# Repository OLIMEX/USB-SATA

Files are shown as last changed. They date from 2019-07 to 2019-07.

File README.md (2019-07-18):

# USB-SATA
USB to SATA converter

# License
Hardware is with CERN OHL v1.2 license

Software is with GPL3 license

Documentation is with CC BY-SA 4.0 license

# USB-SATA Benchmark

[Reference](https://www.thomas-krenn.com/en/wiki/Linux_I/O_Performance_Tests_using_dd)

## Commands
### Streaming I/O
    dd if=/dev/zero of=/mnt/testfile bs=1G count=1 oflag=direct
    dd if=/dev/zero of=/mnt/testfile bs=512M count=1 oflag=direct
    dd if=/dev/zero of=/mnt/testfile bs=256M count=1 oflag=direct

### Latency
    hdparm -W0 /dev/sdx
    dd if=/dev/zero of=/mnt/testfile bs=512 count=1000 oflag=direct

## Results

| Board | Streaming I/O | Latency  |
| ---|---:| ---:|
| PC | 30.2 MB/s | 37.3938 ms |
| A20-MICRO | 28.4 MB/s | 30.5117 ms |
| A10-LIME  | 7.6 MB/s | 33.1223 ms |
| A13-OLXn  | 30.0 MB/s | - |
| A64-OLXn  | 31.5 MB/s | 36.6841 ms |

### PC
#### Streaming I/O
    1073741824 bytes (1.1 GB, 1.0 GiB) copied, 35.5515 s, 30.2 MB/s
** 30.2 MB/s **
### Latency
    512000 bytes (512 kB, 500 KiB) copied, 37.3938 s, 13.7 kB/s
** 37.3938 ms **

## A20-OLinuXino-MICRO
### Streaming I/O
    536870912 bytes (537 MB) copied, 18.9142 s, 28.4 MB/s
** 28.4 MB/s **
### Latency
    512000 bytes (512 kB) copied, 30.5117 s, 16.8 kB/s
** 30.5117 ms ** 

## A10-Lime
### Streaming I/O
    268435456 bytes (268 MB) copied, 35.4505 s, 7.6 MB/s
** 7.6 MB/s **
### Latency
    512000 bytes (512 kB) copied, 33.1223 s, 15.5 kB/s
** 33.1223 ms ** 

## A13-OLinuXino
### Streaming I/O
    268435456 bytes (268 MB) copied, 8.96246 s, 30.0 MB/s
** 30.0 MB/s **

## A64-OLinuXino
### Streaming I/O
    536870912 bytes (537 MB, 512 MiB) copied, 17.0416 s, 31.5 MB/s
** 31.5 MB/s **
### Latency
    512000 bytes (512 kB, 500 KiB) copied, 36.6841 s, 14.0 kB/s
** 36.6841 ms **

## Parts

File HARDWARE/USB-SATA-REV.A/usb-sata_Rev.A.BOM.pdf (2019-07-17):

usb-sata_Rev.A

Designation | Quan-tity | Designator | Package
USB-A MALE | 1 | P3 | USB-A-MALE-SMD
SATA-PWA-07 | 1 | CONN1 | SATA-MALE-7
0402 100 NF 10% 10VDC | 12 | C1,C3,C5,C6,C11,C1 4,C15,C16,C18,C21, C23,C25 | C0402
0603 10 UF 10V 20% | 7 | C2,C4,C12,C13,C17, C22,C24 | C_0603_5MIL_DWS
0402 10 NF X7R 50VDC | 5 | C7,C8,C9,C10,C19 | C0402
0402 20 PF +-0.25 PF | 2 | C26,C27 | C0402
0603 LED RED | 1 | D1 | LED_0603_KA
0603 LED GREEN | 1 | D2 | LED_0603_KA
0402 1 K 5% | 2 | R1,R3 | R_0402_5MIL_DWS
0402 10 K 5% | 4 | R2,R4,R5,R8 | R_0402_5MIL_DWS
0402 4.7 K 5% | 3 | R6,R9,R10 | R_0402_5MIL_DWS
0402 12K 1% | 1 | R7 | R_0402_5MIL_DWS
0402 1 M 5% | 1 | R12 | R_0402_5MIL_DWS
AP1231-3.3V (SOT23-5) | 1 | U1 | SOT-23-5
93LC46C-I/SN (n.a.) | 0 | U2 | SOIC-8
JM20329-LGCA3E | 1 | U3 | LQFP48
SMD3225 12 MHz 10ppm 20pF | 1 | X1 | TSX-3.2x2.5mm_GND(3)
WS02R | 1 | P1 | LIPO_BAT-CON2DW02R
0402 47 K 5% | 1 | R11 | R_0402_5MIL_DWS
0603 1 UF 10V 20% | 1 | C20 | C_0603_5MIL_DWS

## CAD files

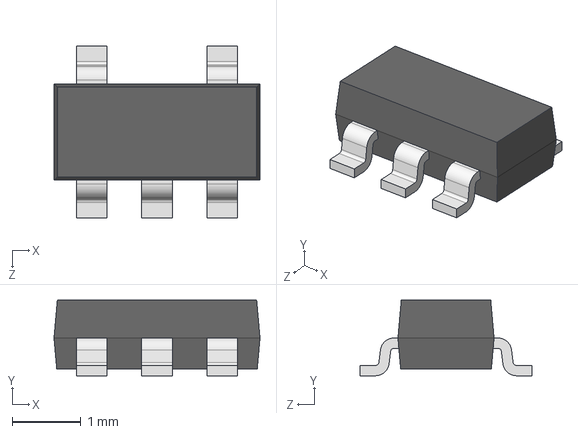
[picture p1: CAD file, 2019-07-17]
HARDWARE/USB-SATA-REV.A/3d/SOT-23-5.step
3.00 x 1.10 x 2.50 mm

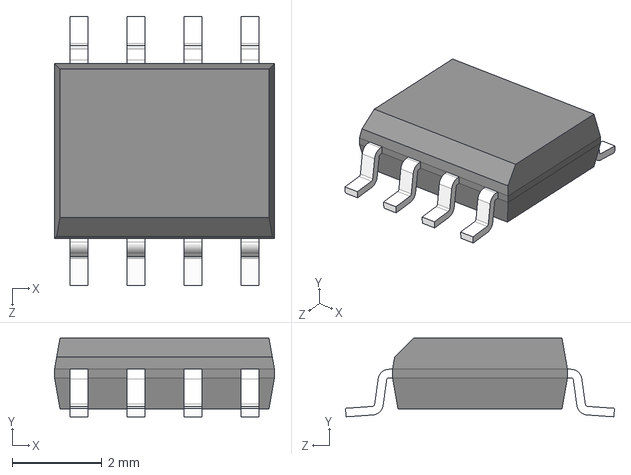
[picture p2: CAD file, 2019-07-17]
HARDWARE/USB-SATA-REV.A/3d/SO-8_150mil---SN65HVDA1050AQDRQ1.STEP
4.90 x 1.75 x 5.99 mm

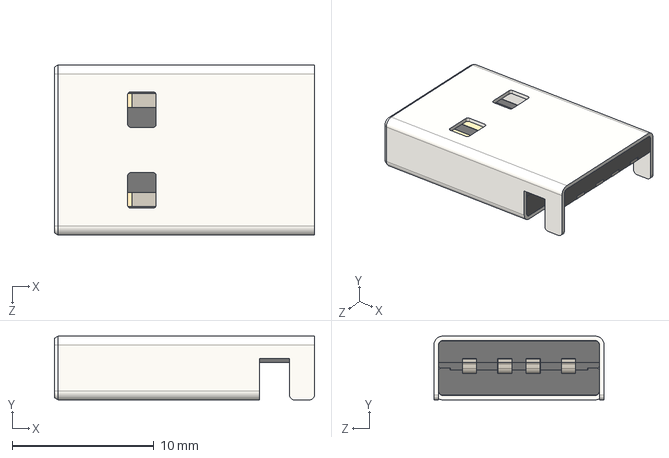
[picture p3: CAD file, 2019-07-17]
HARDWARE/USB-SATA-REV.A/3d/USB-A-MALE.step
18.3 x 4.50 x 12.0 mm

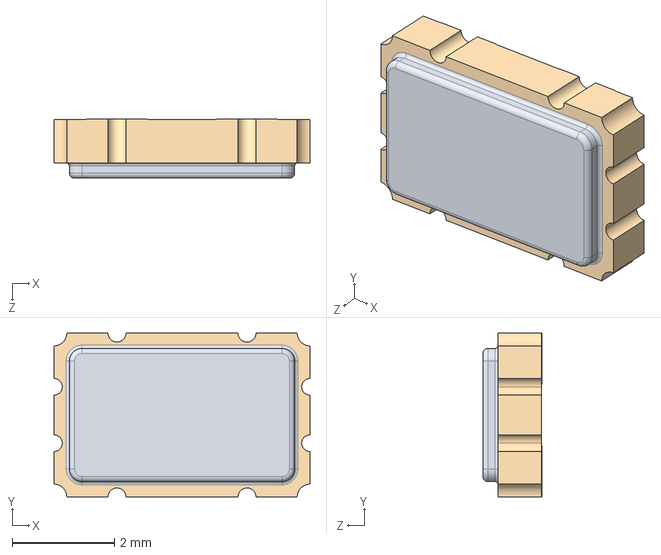
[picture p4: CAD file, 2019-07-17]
HARDWARE/USB-SATA-REV.A/3d/QSG5032.step
5.00 x 3.20 x 1.16 mm

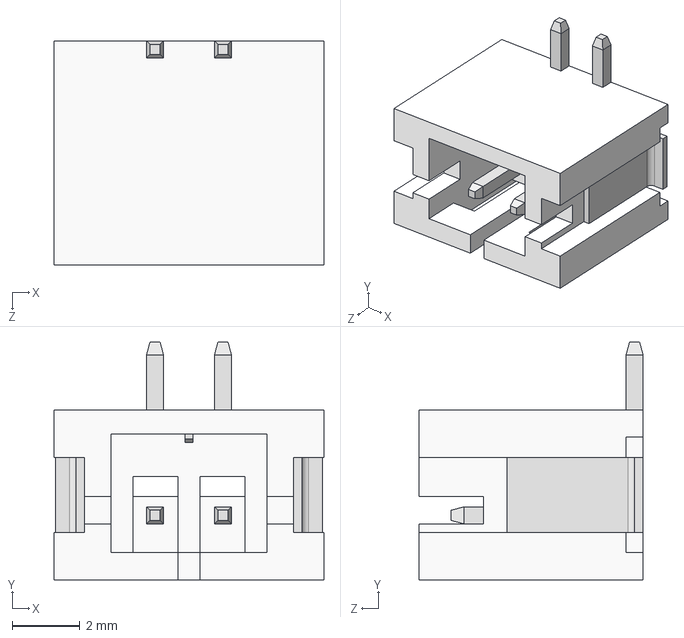
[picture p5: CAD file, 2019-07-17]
HARDWARE/USB-SATA-REV.A/3d/JST_B2B-PH-SM4-TB(DW02R).step
7.95 x 7.00 x 6.60 mm

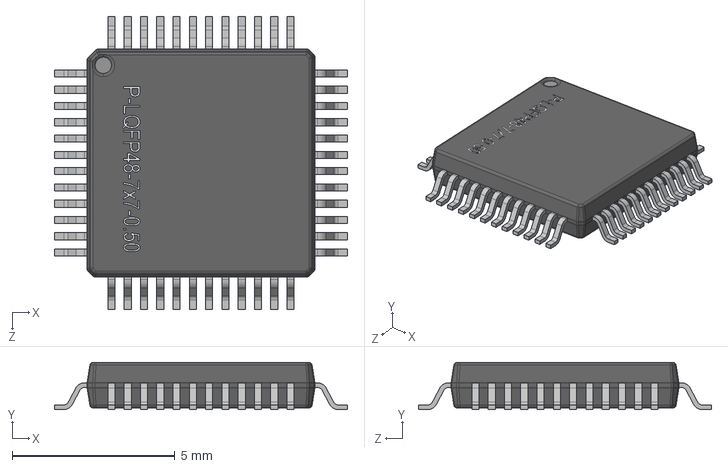
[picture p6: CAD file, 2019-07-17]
HARDWARE/USB-SATA-REV.A/3d/LQFP48-7x7-0_50.step
9.00 x 1.45 x 9.00 mm

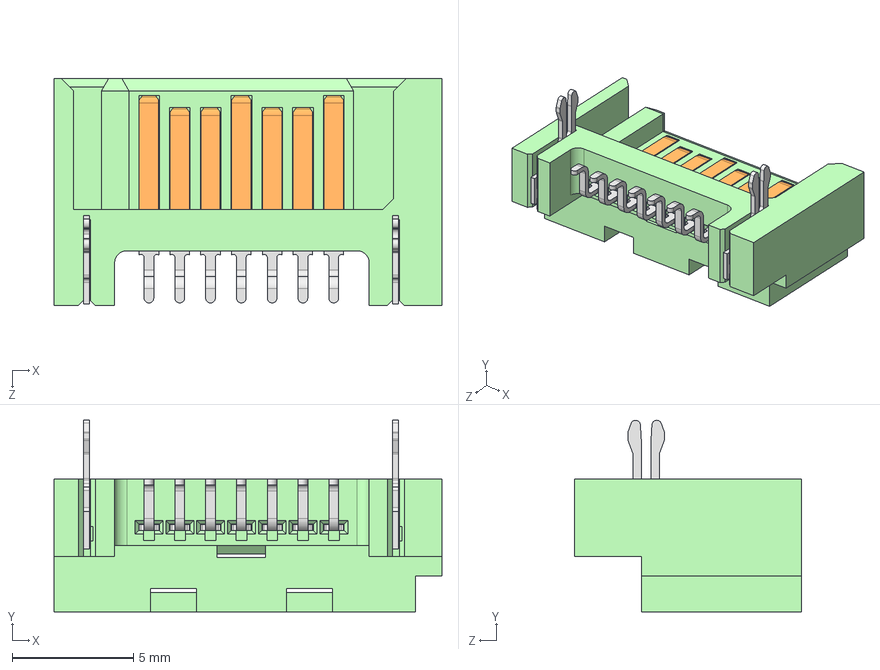
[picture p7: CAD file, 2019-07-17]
HARDWARE/USB-SATA-REV.A/3d/10035692-011.STEP
16.0 x 7.90 x 9.35 mm

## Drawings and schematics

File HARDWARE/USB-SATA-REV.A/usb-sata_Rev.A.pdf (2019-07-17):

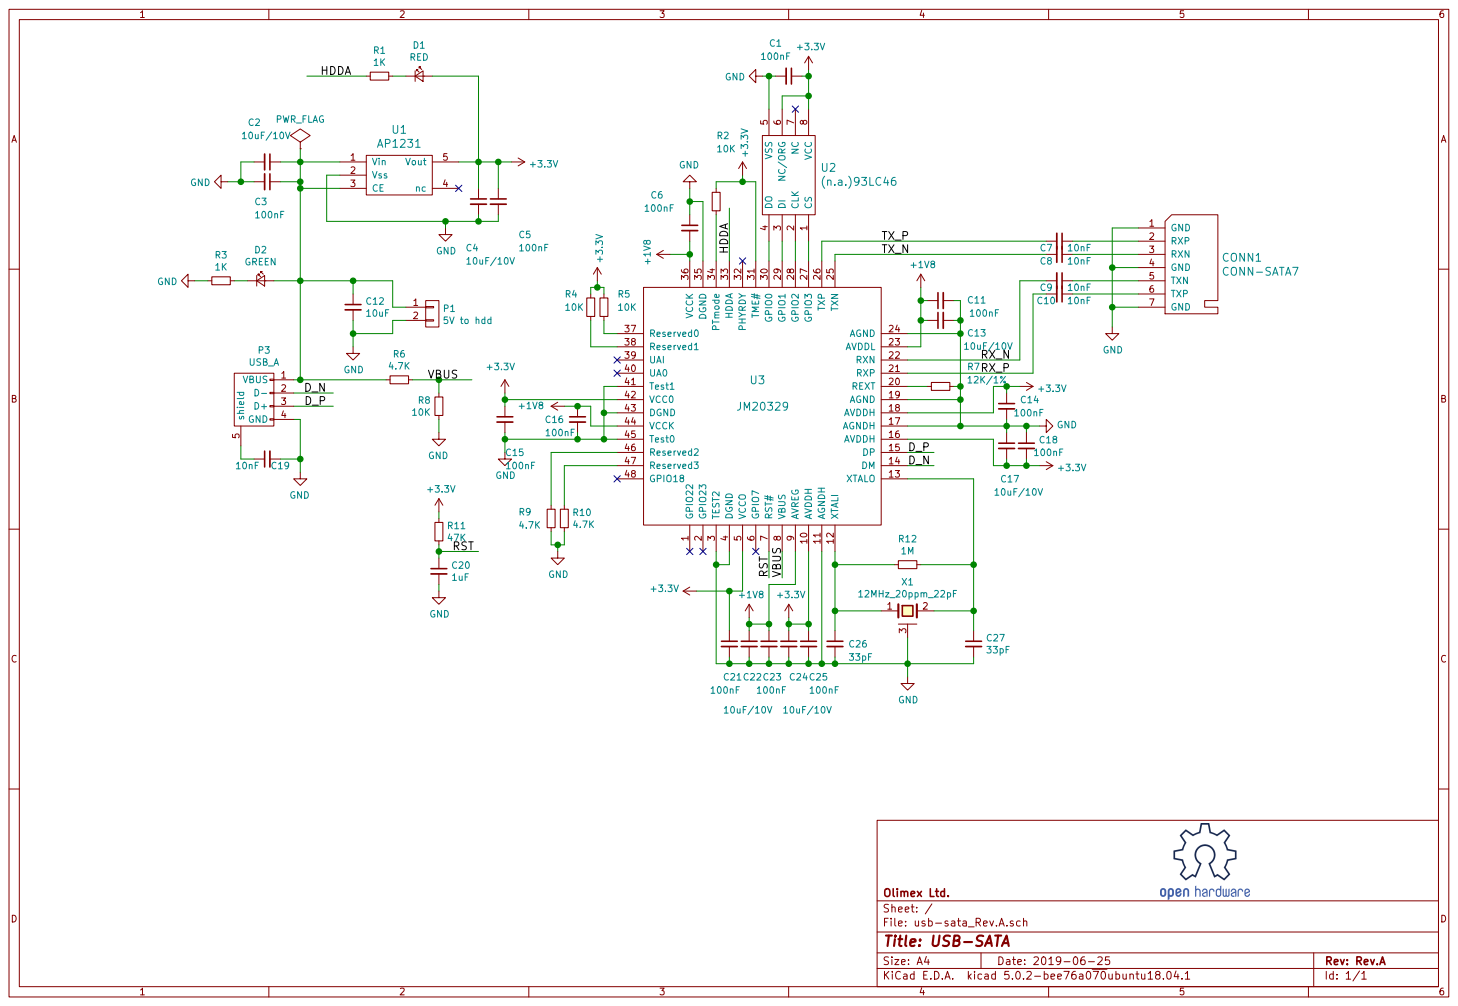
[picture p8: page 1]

3 GPIO0 30 TME# 31 PHYRDY 32 HDDA 33 PTmode 34 DGND 35 VCCK 36 Reserved0 37 Reserved1 38 UAI 39 DGND

2 REXT 20 RXP 21 RXN 22 AVDDL 23 AGND 24 TXN 25 TXP 26 GPIO3 27 GPIO2 28 GPIO1 29 TEST2

1 AVDDH 10 AGNDH 11 XTALI 12 XTALO 13 DM 14 DP 15 AVDDH 16 AGNDH 17 AVDDH 18 AGND 19 GPIO23

File: usb-sata_Rev.A.sch Sheet: / Olimex Ltd. GPIO22

Id: 1/1 Title: USB-SATA

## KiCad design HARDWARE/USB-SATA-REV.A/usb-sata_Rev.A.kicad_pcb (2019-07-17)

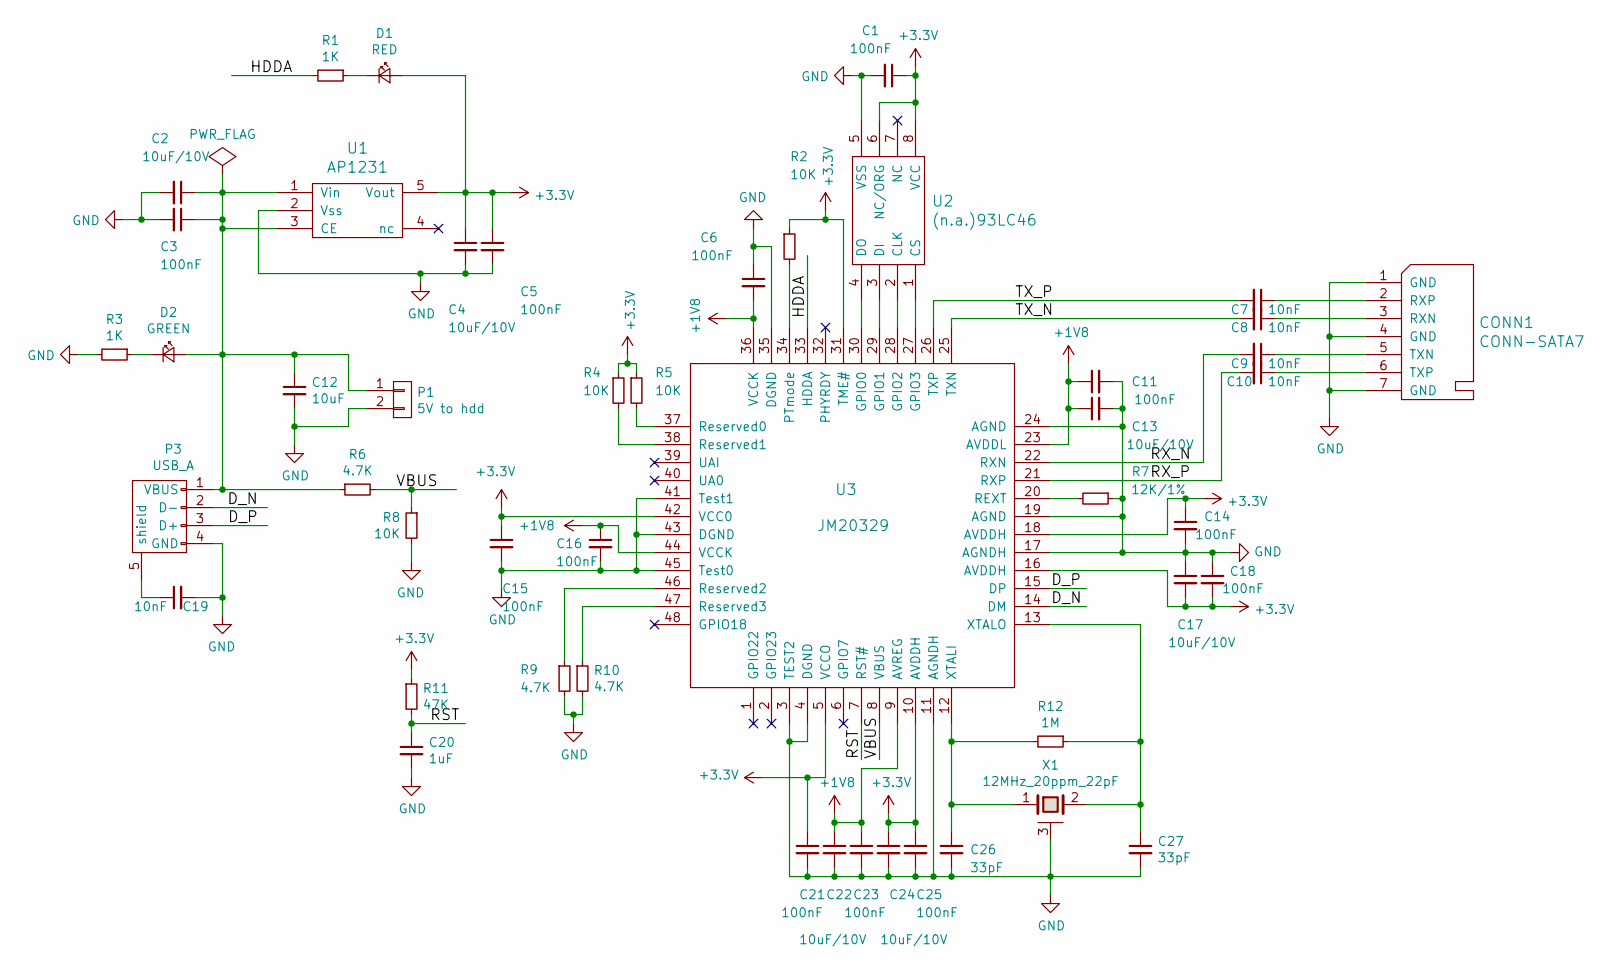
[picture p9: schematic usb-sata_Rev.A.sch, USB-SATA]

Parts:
C1, C3, C5, C6, C11, C14, C15, C16, C18, C21, C23, C25: 100nF; C0402
C2, C4, C13, C17, C22, C24: 10uF/10V; C_0603_5MIL_DWS
C7, C8, C9, C10, C19: 10nF; C0402
C12: 10uF; C_0603_5MIL_DWS
C20: 1uF; C0402
C26, C27: 33pF; C0402
CONN1: CONN-SATA7; SATA-MALE-7
D1: RED; LED_0603_KA
D2: GREEN; LED_0603_KA
P1: 5V to hdd; LIPO_BAT-CON2DW02R
P3: USB_A; USB-A-MALE-SMD
R1, R3: 1K; R_0402_5MIL_DWS
R2, R4, R5, R8: 10K; R_0402_5MIL_DWS
R6, R9, R10: 4.7K; R_0402_5MIL_DWS
R7: 12K/1%; R_0402_5MIL_DWS
R11: 47K; R_0402_5MIL_DWS
R12: 1M; R_0402_5MIL_DWS
U1: AP1231; SOT-23-5
U2: (n.a.)93LC46; SOIC-8
U3: JM20329; LQFP48
X1: 12MHz_20ppm_22pF

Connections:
+1V8: C6.2, C11.1, C13.1, C16.1, C22.1, C23.1, U3.9 (AVREG), U3.23 (AVDDL), U3.36 (VCCK), U3.44 (VCCK)
+3V3: C1.1, C4.1, C5.1, C14.1, C15.1, C17.2, C18.2, C21.1, C24.1, C25.1, D1.2 (A), R2.1, R4.1, R5.1, R11.1, U1.5 (Vout), U2.6 (NC/ORG), U2.8 (VCC), U3.5 (VCCO), U3.10 (AVDDH), U3.16 (AVDDH), U3.18 (AVDDH), U3.31 (TME#), U3.42 (VCC0)
/D_N: P3.2 (D-), U3.14 (DM)
/D_P: P3.3 (D+), U3.15 (DP)
/HDDA: R1.2, U3.33 (HDDA)
/RST: C20.1, R11.2, U3.7 (RST#)
/RX_N: C9.2, U3.22 (RXN)
/RX_P: C10.2, U3.21 (RXP)
/TX_N: C8.2, U3.25 (TXN)
/TX_P: C7.2, U3.26 (TXP)
/VBUS: R6.2, R8.1, U3.8 (VBUS)
GND: C1.2, C2.2, C3.2, C4.2, C5.2, C6.1, C11.2, C12.2, C13.2, C14.2, C15.2, C16.2, C17.1, C18.1, C19.2, C20.2, C21.2, C22.2, C23.2, C24.2, C25.2, C26.2, C27.2, CONN1.1 (GND), CONN1.4 (GND), CONN1.7 (GND), P1.2, P3.4 (GND), R3.2, R7.1, R8.2, R9.2, R10.2, U1.2 (Vss), U2.5 (VSS), U3.3 (TEST2), U3.4 (DGND), U3.11 (AGNDH), U3.17 (AGNDH), U3.19 (AGND), U3.24 (AGND), U3.35 (DGND), U3.41 (Test1), U3.43 (DGND), U3.45 (Test0), X1.3 (case)
unnamed: C7.1, CONN1.2 (RXP)
unnamed: C8.1, CONN1.3 (RXN)
unnamed: C9.1, CONN1.5 (TXN)
unnamed: C10.1, CONN1.6 (TXP)
unnamed: C2.1, C3.1, C12.1, D2.2 (A), P1.1, P3.1 (VBUS), R6.1, U1.1 (Vin), U1.3 (CE)
unnamed: C19.1, P3.5 (shield)
unnamed: C26.1, R12.2, U3.12 (XTALI), X1.1
unnamed: C27.1, R12.1, U3.13 (XTALO), X1.2
unnamed: D1.1 (K), R1.1
unnamed: D2.1 (K), R3.1
unnamed: R2.2, U3.34 (PTmode)
unnamed: R4.2, U3.38 (Reserved1)
unnamed: R5.2, U3.37 (Reserved0)
unnamed: R7.2, U3.20 (REXT)
unnamed: R9.1, U3.46 (Reserved2)
unnamed: R10.1, U3.47 (Reserved3)
unnamed: U2.1 (CS), U3.27 (GPIO3)
unnamed: U2.2 (CLK), U3.28 (GPIO2)
unnamed: U2.3 (DI), U3.29 (GPIO1)
unnamed: U2.4 (DO), U3.30 (GPIO0)

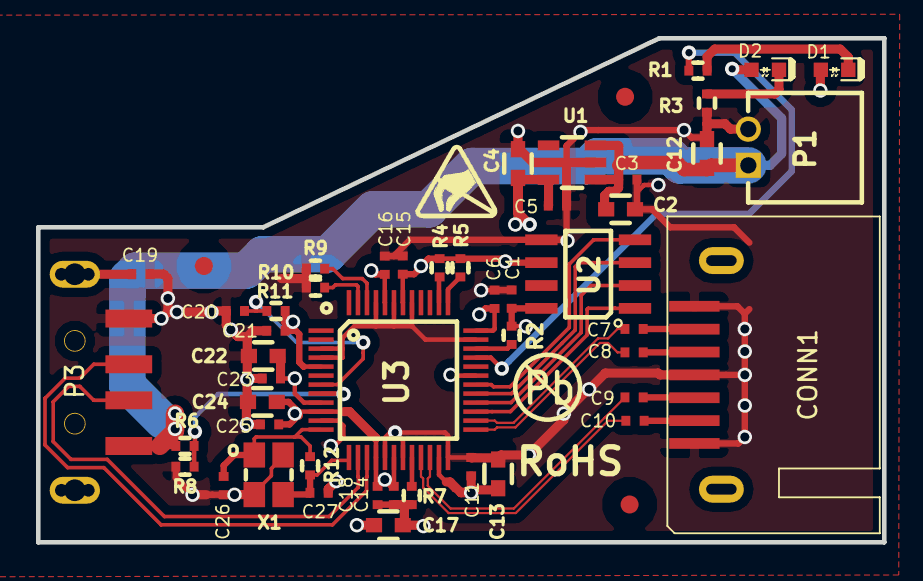
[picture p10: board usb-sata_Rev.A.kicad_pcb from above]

Board: 4 copper layers, 47.0 x 28.0 mm, 49 parts (0 on the bottom side), 32 nets.

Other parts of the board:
Ref**: Val**; LOGO_ANTISTATIC_SMALL_4.5mmX2.8mm
